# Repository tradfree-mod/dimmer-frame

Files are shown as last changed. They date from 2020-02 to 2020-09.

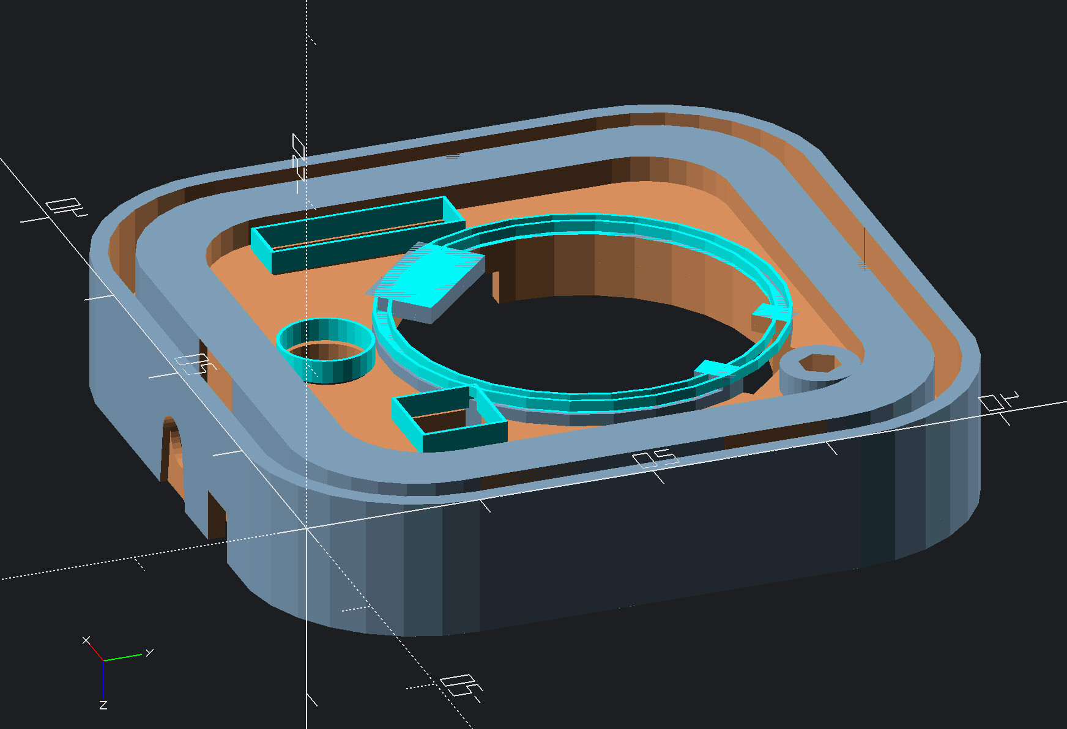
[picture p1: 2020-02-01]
img/supports-easy-bottom.jpg

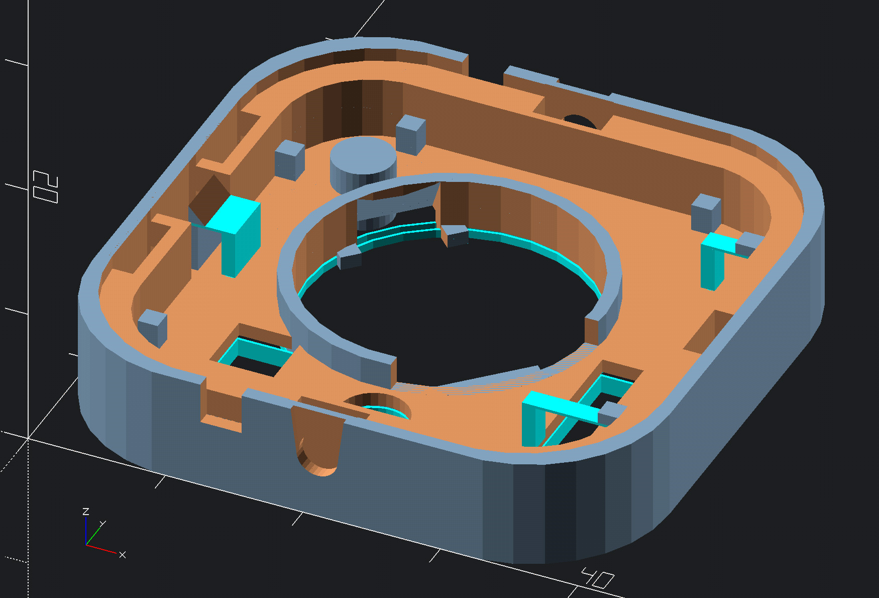
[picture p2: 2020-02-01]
img/supports-easy-top.jpg

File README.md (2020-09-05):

# IKEA TRÅDFRI dimmer 3D-printable frame

 

This is a 3D-printable replica of the IKEA lights dimmer frame.

There are two configations:

- One is compatible with the original IKEA bottom lid, and can be used
  as a replacement for it (`bottom-case-ikea.stl`)
- One also exposes the SWD debug header and will be compatible
  with our [debug chip](https://github.com/tradfree-mod/hardware) and
  bottom lid (which we haven't finished yet) (`bottom-case.stl`)

Note that, since 3D-printed clips are quite fragile and they easily
break if you try to fit in the PCB, we decided that the best way to
hold the PCB in place would be a slide-in holder. You can find it in
the prebuilt STL downloads under `other/pcb-holder.stl`. It slides in
on the side and in our tests it's a lot stronger than a regular clip.

## Building the design

Prebuilt STL downloads:
https://gitlab.com/tradfree/bottom-case/-/jobs/artifacts/master/browse?job=render

The design can be built in two ways:

- By opening one of the `.scad` files with OpenSCAD (tweak the
  the settings in `config.scad`)
- With make:

    ```
    make case  # Case with SWD hole, screw hole in a different position
    make case-ikea  # Compatible with the original IKEA lid
    ```

## Support material

Since the part is very small and has a lot of tiny parts and clips,
it is practically impossible to print it without supports or with
normal slicer auto-generated supports.

For this reason, we decided to include tailor-made supports in the
model itself. There are two types of supports:

- "easy": supports on the battery (bottom) side. Easier to print and
  remove because there aren't too many floating parts, but it won't
  look as good.
- "hardcore": supports on the PCB (top) side. Huge amount of supports,
  takes 10 minutes and a lot of care to remove. Top part is going to
  look bad but you're going to cover it with the PCB, so you'll only
  see it once ;)

Supports can either be enabled in `config.scad` by setting
`build_supports` to `"easy"` or `"hardcore"`, and disabled by setting
it to `"none"`, or with `make` by passing
`'-Dbuild_supports="easy/hardcore"'` (yes you need the quotation marks)

Under [/img](/img) you can find a preview of the supports (in cyan)
that you can use as reference for removal. Be careful because OpenSCAD
colored the bottom of the battery clips cyan but they're not to be
removed.

Also beware that the bridge-y supports are supposed to be clipped off,
not to be torn off. Cut them off with a clipper.

### Important

The build does **not** flip the model if you build it with "hardcore"
supports, you need to rotate it 180° before slicing.

## Print settings

It's very important to adjust print settings otherwise the print isn't
gonna be any good.

I suggest you use either Slic3r or Slic3r++ (fork by supermarill) and
not Cura. In my experience Cura wasn't able to detect some bridges and
it would generate spaghetti.

- Disable supports (unless you're using soluble supports)
- Enable thin wall detection and (if available) set it to the smallest
  wall size detection available
- Layer height: 1.5mm
- Optionally enable top surface ironing:
  - Cura: find "Ironing"
  - Slic3r++: set top surface pattern to "ironing"
- Use slow print speeds
- Enable bridge detection and optimization if available
- Set fan to always, 100%, if available
- Remember to rotate the model if using "hardcore" supports

## Troubleshooting

### Screw hole is too wide/tight

Tweak it in `config.scad`

### Can't push battery in

Make sure you've scraped the supports away well enough. Insert the battery
from the PCB side: it must be flush with the battery housing on the other
side.

You can tweak the battery clip sizes in `include/sizes.scad`, change
`battery_small_clip_dimens` and `battery_big_clip_dimens`.

### PCB doesn't click in

Make sure the battery is flush with its housing. Also make sure you didn't
break the clips.

## License



This work is licensed under a [Creative Commons Attribution-ShareAlike 4.0 International License](https://creativecommons.org/licenses/by-sa/4.0/).

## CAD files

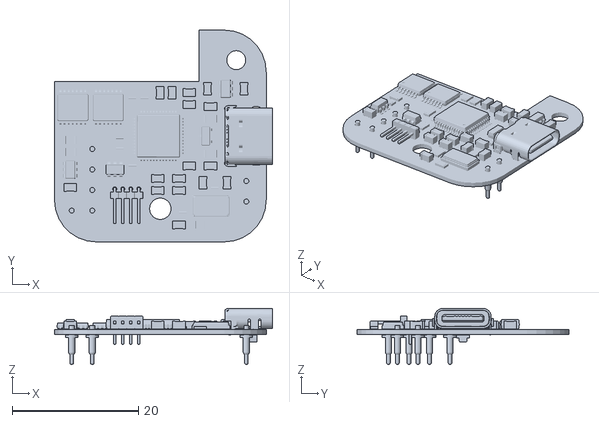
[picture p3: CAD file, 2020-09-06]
zigbee_coordinator3.stl
34.5 x 33.5 x 8.87

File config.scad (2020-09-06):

screw_diam=2;

// For custom bottom lid
screw_pos=[9, 33];

// Set to false if you want to use it with the IKEA bottom lid
carve_swd_hole=true;

// Custom bottom lid support clip, set to false if using the IKEA lid
custom_case_clip=true;

screw_hole_fn=6;

build_supports="none";

supports_thickn=0.2;
supports_contanct_z_dist=0.2; // detachable (hopefully)

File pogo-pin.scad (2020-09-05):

tip_rad=0.3;
tip_len=1.5;
body_rad=0.5;
body_len=2.8;
ring_rad=1;
ring_len=0.4;
solder_tip_rad=0.4;
solder_tip_len=1.5;
fn=50;


translate([0, 0, tip_len+body_len+ring_len])
rotate([180, 0, 0])
union() {
	translate([0, 0, tip_len+body_len+ring_len]) {
		cylinder(r=solder_tip_rad, h=solder_tip_len, $fn=fn);
	}

	translate([0, 0, tip_len+body_len]) {
		cylinder(r=ring_rad, h=ring_len, $fn=fn);
	}

	translate([0, 0, tip_len+body_rad]) {
		cylinder(r=body_rad, h=body_len-body_rad, $fn=fn);
		sphere(r=body_rad, $fn=fn);
	}

	translate([0, 0, tip_rad]) {
		cylinder(r=tip_rad, h=tip_len-tip_rad+1, $fn=fn);
		sphere(r=tip_rad, $fn=fn);
	}
}

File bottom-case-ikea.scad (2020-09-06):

include <config.scad>
include <include/sizes.scad>
include <include/modules.scad>
include <parts/main_body.scad>

// Overrides for IKEA original bottom lid
screw_pos=[
    33.5,
    21
];
carve_swd_hole=false;
custom_case_clip=false;

mainBody();

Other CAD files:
bottom-case.scad
custom_lid.scad
include/modules.scad
include/sizes.scad
include/supports.scad
parts/custom_lid.scad
parts/main_body.scad
parts/main_body_supports.scad
pcb-holder.scad

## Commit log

2020-01-28 Add most details
    [main_body.scad, modules.scad, sizes.scad]
2020-01-28 Add pogo pin
    [pogo-pin.scad]
2020-01-28 Flip pogo pin
    [pogo-pin.scad]
2020-01-28 Add battery clips
    [main_body.scad, sizes.scad]
2020-01-28 Add clips and screw hole
    [main_body.scad, modules.scad, sizes.scad]
2020-01-28 Raise face number for round parts render quality
    [sizes.scad]
2020-01-28 Clean up sizes.scad
    [sizes.scad]
2020-01-28 Add rendered STLs
    [main.stl, pogo-pin.stl]
2020-01-28 Add option to build an IKEA-compatible frame
    [main_body.scad, sizes.scad]
2020-01-28 Add battery removal screwdriver slot
    [main_body.scad, modules.scad, sizes.scad]
2020-01-28 Update STL
    [main.stl]
2020-01-29 Add hinge holes and alignment notches
    [main_body.scad, modules.scad, sizes.scad]
2020-01-29 Add other SCAD to build IKEA-compatible frame
    [bottom-case-ikea.scad, bottom-case.scad]
2020-01-29 Also create directories in CI script
    [main.stl]
2020-01-29 Remove STLs as they're built in the CI
    [main.stl, pogo-pin.stl]
2020-01-29 Do not build screw hole with $fn=500 on GitLab CI
2020-01-29 Add slots for bottom lid clips
    [main_body.scad, sizes.scad]
2020-01-30 Increase PCB housing size after testing
    [sizes.scad]
2020-01-30 Reduce battery hole size
    [sizes.scad]
2020-01-30 Add optional 3D printing supports
    [bottom-case-ikea.scad, config.scad, main_body.scad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]
2020-01-30 Build STL with supports in GitLab CI
2020-01-30 Avoid cutting close to another surface
    Avoids visual artifacts during preview
    [main_body.scad]
2020-01-30 Add "hardcore" optional supports on the other side
    [config.scad, main_body.scad, main_body_supports.scad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]
2020-01-30 Fix battery clips hardcore supports
    [main_body_supports.scad, sizes.scad]
2020-01-30 Fix IKEA-compatible model build
    [bottom-case-ikea.scad]
2020-01-31 Don't build supports by default
    [config.scad]
2020-01-31 Increase PCB size again
    [main_body_supports.scad, sizes.scad]
2020-01-31 Improve battery hole suppports
    [main_body_supports.scad, supports.scad]
2020-02-01 Increase PCB big clip size
    [sizes.scad]
2020-02-01 Fix STL link
2020-02-01 Remove alignment notches supports
    They're not needed and are just painful to remove
    [main_body_supports.scad]
2020-02-01 Revert "Reduce battery hole size"
    This reverts commit 69e2cf4bcebed365f6b5309c8f552e8bdbd7508d.
    [sizes.scad]
2020-02-01 Reduce battery small clips size
    They have to be very tiny, otherwise you'll need a hammer
    to put the battery in.
    [sizes.scad]
2020-02-01 Fix battery clips thickness
    [sizes.scad]
2020-02-01 Replace big PCB clip with small holder pin
    [main_body.scad, main_body_supports.scad, pcb-holder.scad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]
2020-02-01 Make directories for pcb-holder and stuff
2020-02-02 Fix lid clip slots size
    [main_body.scad]
2020-02-02 Also add slots for our custom lid
    [main_body.scad, sizes.scad]
2020-02-02 Make corner radii consistent
    [sizes.scad]
2020-02-02 Begin work on custom lid
    [custom_lid.scad, sizes.scad]
2020-07-09 Add notes about the PCB holder
2020-09-05 Sync old changes
    [custom_lid.scad, pogo-pin.scad, sizes.scad]
2020-09-06 Add untested custom lid
    [bottom-case-ikea.scad, config.scad, custom_lid.scad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]

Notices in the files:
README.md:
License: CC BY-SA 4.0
